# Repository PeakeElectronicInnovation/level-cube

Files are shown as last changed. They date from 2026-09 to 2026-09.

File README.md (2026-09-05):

# Level Cube

A pocket-sized two-axis spirit level. An ADXL345 accelerometer measures tilt and an 8x7 matrix of
WS2812B LEDs shows a "bubble" that drifts toward the high side of whatever surface the cube is
resting on. Green means level, amber means close, red means off. One button does everything.

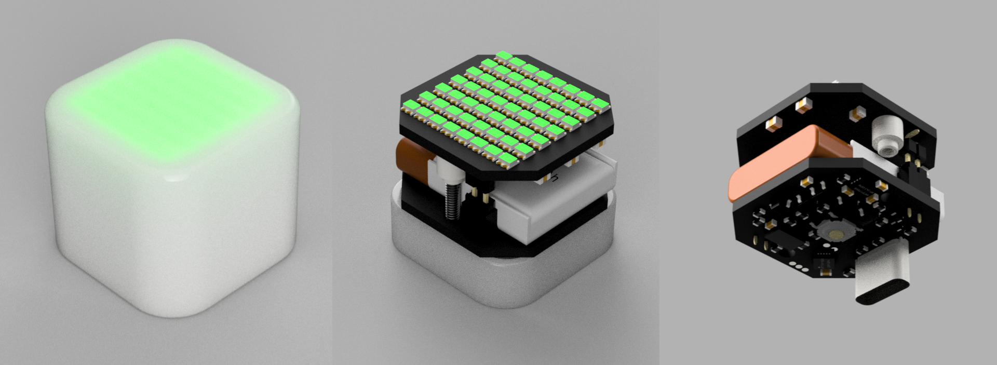
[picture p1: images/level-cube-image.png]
Level Cube - enclosure, LED matrix, main PCB


Firmware runs on an ATtiny1606 (16 KB flash, 1 KB RAM) using PlatformIO + megaTinyCore, powered by a
single LiPo cell with USB-C charging.

---

## Contents

- [Features](#features)
- [Using it](#using-it)
- [Hardware](#hardware)
- [Firmware](#firmware)
- [Building and flashing](#building-and-flashing)
- [Tuning](#tuning)
- [Repository layout](#repository-layout)
- [Credits and licence](#credits-and-licence)

---

## Features

- Two-axis level with a smoothly interpolated bubble (sub-pixel positioning across 2x2 LEDs).
- Works on any face of the cube: the button selects which sensor axis is "up" (X/Y/Z), the
  firmware works out whether the board is right-way-up or flipped and rotates the display so the
  UI always reads correctly.
- Per-orientation zero calibration stored in EEPROM, so the bubble reads dead centre on a known
  level surface for each of the five supported orientations.
- Soft power latch: a momentary button press turns the cube on, the MCU holds itself on, and either
  a long press or one minute of stillness turns it off (near-zero standby draw).
- Battery gauge on power-up, low-battery cut-off, USB-C LiPo charging.
- Whole thing runs in 337 bytes of RAM and 7.5 KB of flash. No floating point in the main loop.

---

## Using it

### Power on

Press the button. The cube shows:

1. **Battery gauge** - a horizontal bar across the middle row for ~0.7 s. Green above 50 %,
   amber 20-50 %, red below 20 %. If the cell is below 3.4 V the display flashes red three times
   and the cube turns itself off again.
2. **Axis glyph** - a large `X`, `Y` or `Z` for 0.5 s showing which sensor axis has been chosen as
   "up". On power-up this is auto-detected from gravity.
3. **Level display**.

### Level display

- Dim white **ticks** at the centre of each edge mark the level position.
- The **bubble** moves toward the high side of the surface, like a real spirit level. Full-scale
  deflection (bubble reaching the edge) is about 10 degrees.
- Bubble colour: **green** within ~1 degree, **amber** within ~3 degrees, **red** beyond that.

### Button

| Action | Result |
|---|---|
| Short press (< 2 s) | Cycle the "up" axis X -> Y -> Z. The glyph is shown briefly. |
| Hold 2-5 s, release | Power off. A **white** bar fills along the bottom row while held. |
| Hold > 5 s, release | Start calibration. The bar turns **red** during 2-5 s, then **blue** once 5 s is passed. |

The bar gives you feedback so you know which action you will get when you let go.

### Orientation

The ADXL345 has three axes. Whichever one is chosen as "up" is ignored for levelling; the other two
drive the bubble. For X and Y the sign of gravity along the up axis is detected automatically (with
0.5 g of hysteresis so it doesn't flicker), giving five cases:

| Case | Up axis | Bubble columns from | Bubble rows from | Display rotation |
|---|---|---|---|---|
| 0 | +X | Z | Y | column 0 at top |
| 1 | -X | Z | Y | column 7 at top |
| 2 | +Y | X | Z | normal |
| 3 | -Y | X | Z | 180 degrees |
| 4 | Z (either sign) | X | Y | normal (board flat) |

Case 4 is the "cube sitting on its base" case. Cases 0-3 are for standing the cube on a side and
using an edge as the reference. The mapping and signs are in `AXIS_MAP` in `include/config.h`.

### Calibration

Each of the five cases has its own pair of zero offsets. To calibrate:

1. Select the axis you want to calibrate (short presses until the correct glyph shows).
2. Hold the button until the hold bar turns blue (> 5 s), then release.
3. A **5-4-3-2-1 countdown** is shown. Put the cube down on your reference surface and take your
   hands off it.
4. A blue dot chases around the perimeter for 1.5 s while 150 raw samples are averaged; a blue bar
   in the centre row shows progress.
5. A green **tick** confirms the offsets have been saved to EEPROM.

The offsets are applied immediately and survive power cycles. Calibrating one case does not affect
the others.

### Auto power off

If no axis changes by more than ~0.7 degrees for 60 seconds (checked every 500 ms), and the
button hasn't been touched, the cube powers itself off.

---

## Hardware

Two PCBs stacked inside a translucent cube enclosure that acts as the diffuser. Design files
(Altium) and a PDF of the schematics are in `hardware/`.

| | |
|---|---|
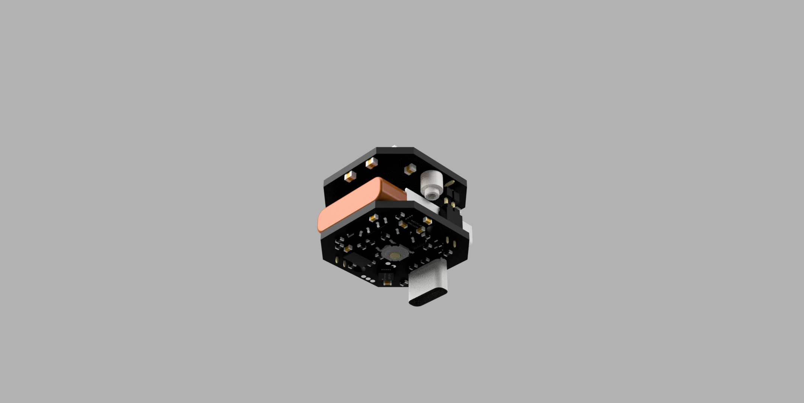
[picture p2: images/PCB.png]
Main PCB
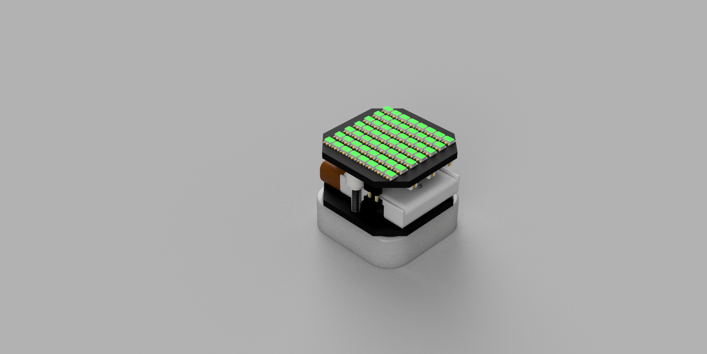
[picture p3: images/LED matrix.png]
LED matrix
|  |  |
| Main board (underside): MCU, accelerometer, charger, USB-C, button | LED panel stacked on pin headers above the main board and battery |

### Main board

| Function | Part | Notes |
|---|---|---|
| MCU | **ATtiny1606** (QFN20) | 16 KB flash, 1 KB SRAM, 256 B EEPROM. Programmed via UPDI on PA0. |
| Accelerometer | **ADXL345BCCZ** | I2C, address `0x53` (SDO/ALT pulled low). INT1/INT2 routed to PA5/PA6 but not used. |
| LiPo charger | **MCP73832** | PROG = 5.1 k -> ~200 mA charge current. STAT output to PC3. |
| 3.3 V regulator | **LR7533** LDO | Powers the MCU and accelerometer (`+3.3`). |
| Charge port | **USB-C** receptacle | Power only. 5.1 k pull-downs on CC1/CC2 so a C-to-C cable supplies 5 V. |
| Power latch | PMOS Q1 + NMOS Q3 | See below. |
| LED power switch | PMOS Q2 + NMOS Q4 | LED matrix supply is switched separately from the MCU. |
| Button | SW1 | Momentary, active low, to PC2 (internal pull-up). |
| Battery sense | 100 k / 100 k divider | VBAT/2 to PA1. |
| USB sense | 100 k / 100 k divider | VBUS/2 to PA2 (not currently used by firmware). |
| Battery | single LiPo cell on solder pads | Nominal 3.7 V. |

### Power path

```
                  Q1 (PMOS)                      Q2 (PMOS)
  VBAT ───────────┬──────┬── VMCU ── LR7533 ── +3.3 (MCU, ADXL345)
                  │      │
                  │      └──────────┬── VLED ── WS2812B matrix (56x)
                  │                 │
            gate ─┴─ R1 100k        gate ─ R7 100k
              │                       │
       ┌──────┴──────┐             Q4 (NMOS) <── LED_PWR (PC1)
   D1 ─┤             │
   SW1 (button)   Q3 (NMOS) <── PWR (PC0)
```

- **Power on**: pressing the button pulls Q1's gate low through D1, powering the MCU. The very
  first thing `setup()` does is drive `PWR` (PC0) high, which turns on Q3 and keeps Q1 on after
  the button is released.
- **Power off**: the firmware drives `PWR` low. Q1 turns off and everything downstream of it loses
  power. Standby current is just the leakage through the charger and the FET.
- **LEDs**: the matrix is fed straight from the battery through Q2, enabled by `LED_PWR` (PC1).
  The 3.3 V data line drives the first WS2812B directly. The firmware turns the LED supply off
  (after clearing the frame) before pulling `PWR` low, so the matrix never sees a dirty shutdown.

### LED panel

A separate board carrying **56 x WS2812B** in an 8 wide x 7 tall grid, chained in a single
string, addressed left to right and top to bottom (LED index = `y * 8 + x`). It plugs onto the main
board via pin headers: `L_V+`, `L_GND` and `LED_DAT`.

At full white the matrix could draw around 3 A, so the firmware caps brightness (bubble 48/255,
UI elements 24/255, ticks 3/255). Through the diffuser this is plenty.

### MCU pin map

| Pin | Signal | Direction | Use |
|---|---|---|---|
| PA0 | UPDI | - | Programming/debug |
| PA1 | BATT_VOLTS | analog in | Battery voltage, VBAT/2 |
| PA2 | USB_VOLTS | analog in | VBUS/2 (unused) |
| PA3 | SPI0 SCK | internal | Bit clock for the LED driver, not routed off-chip |
| PA4 | ANA_FLOAT | - | Spare, floating |
| PA5 | AXL_INT1 | in (pull-up) | ADXL345 INT1 (unused) |
| PA6 | AXL_INT2 | in (pull-up) | ADXL345 INT2 (unused) |
| PA7 | LED_DAT | out | WS2812B data, CCL LUT1 output |
| PB0 | SCL | I2C | ADXL345 |
| PB1 | SDA | I2C | ADXL345 |
| PB2 | TX | out | Debug UART, 115200 (only when built with `-DDEBUG`) |
| PB3 | RX | in | Debug UART |
| PC0 | PWR | out | Power latch, drive high to stay on |
| PC1 | LED_PWR | out | LED matrix supply enable |
| PC2 | BUTTON | in (pull-up) | Active low |
| PC3 | CC_STAT | in (pull-up) | MCP73832 charge status (read, not yet displayed) |

---

## Firmware

### Overview

```
src/main.cpp       power latch, button state machine, orientation, calibration, auto-off, UI
src/display.*      LED frame buffer, drawing primitives, WS2812B output via CCL + SPI + TCB0
src/accel.*        minimal ADXL345 driver and EMA filter
include/config.h   pins, timings, thresholds, AXIS_MAP
include/characters.h  4x6 glyphs for digits and X/Y/Z
lib/SmoothLedCcl/  vendored WS2812 bit-banging-free driver (see below)
```

The main loop is cooperative and non-blocking: poll the accelerometer at 100 Hz, poll the button,
check for movement, check the battery every 5 s, and render a frame every 25 ms (~40 Hz).

### LED driving without bit-banging

Generating WS2812B timing on an 8-bit part while doing anything else is awkward. This project uses
the approach from Matt Shepcar's [SmoothLed](https://github.com/mattshepcar/SmoothLed): the
**SPI0** peripheral shifts the pixel bytes out, an event channel feeds SCK into **TCB0** in
single-shot mode to produce the "1-bit" pulse width, and a **CCL** look-up table (LUT1, output on
PA7) combines SCK, MOSI and the TCB output into a valid WS2812B waveform. The CPU's only job is to
refill the SPI data register from an interrupt (`ISR(SPI0_INT_vect)` in `display.cpp`), which is
why the bytes are written inverted (the LUT expects `!MOSI`).

The result is that a full 168-byte frame streams out in the background while the main loop keeps
running. `display_show()` starts a transfer; every drawing call waits for any in-flight transfer to
finish before touching the buffer.

`SmoothLedCcl.h` is vendored in `lib/SmoothLedCcl/` rather than pulled from the registry because
the upstream `PC0_SPI0_ASYNCCH2` branch references `EVSYS_ASYNCCH2`, which tinyAVR **0-series**
parts don't have. The vendored copy guards that branch so it compiles on the ATtiny1606.

TCB0 is taken by the LED driver, so `millis()` must run on TCA0. The PlatformIO board definition
for the ATtiny1606 already defines `MILLIS_USE_TIMERA0`; if you build with a different board or
core configuration, make sure that define is present or the two will fight over TCB0.

### Coordinate systems

`display.h` keeps two frames of reference:

- **Board coordinates** are fixed to the PCB (x 0-7, y 0-6). The bubble is drawn here because its
  position is physically meaningful no matter how the cube is held.
- **View coordinates** are what the person looking at the cube sees after the current rotation
  is applied. Glyphs, bars, ticks and the perimeter chaser are drawn here so they always appear
  upright. For the two 90 degree cases the view is 7 wide by 8 tall.

### Accelerometer and filtering

The ADXL345 runs at 100 Hz in full-resolution +/-2 g mode (3.9 mg/LSB, so 1 g is ~256 LSB). Each
axis is smoothed with an exponential moving average in Q8 fixed point:

```
y += (x - y) >> 4        // tau ~ 160 ms at 100 Hz
```

Tilt is then handled as Q4 LSB values. For small angles `LSB ~= 256 * sin(angle)`, which is where
the thresholds in `config.h` come from (4.5 LSB ~ 1 degree, 13.4 LSB ~ 3 degrees, 45 LSB ~ 10
degrees). Calibration averages *raw* (unfiltered) samples over the 1.5 s window so the filter's
lag doesn't bias the result.

### EEPROM layout

| Address | Contents |
|---|---|
| 0 | Magic byte `0xA5` (offsets valid) |
| 1-20 | `int16_t calOffset[5][2]` - per case `[col, row]` zero offsets in Q4 LSB |

If the magic byte is missing all offsets are treated as zero.

### Resource usage

```
RAM:   337 / 1024 bytes  (168 of which is the LED frame buffer)
Flash: 7550 / 16384 bytes
```

---

## Building and flashing

Requires [PlatformIO](https://platformio.org/) (CLI or VS Code extension). The `atmelmegaavr`
platform and megaTinyCore are fetched automatically on first build.

```sh
pio run                  # build
pio run -t upload        # flash via UPDI (Atmel-ICE by default, see platformio.ini)
```

Connect the programmer to the UPDI pad (PA0), GND and 3.3 V. To use a different UPDI programmer
(e.g. SerialUPDI, pymcuprog, jtag2updi) change `upload_protocol` in `platformio.ini`.

### Debug output

Build with `DEBUG` defined to get a 115200 baud log on PB2 (power-up, axis changes, case changes,
battery voltage, calibration results, and periodic tilt values):

```powershell
$env:PLATFORMIO_BUILD_FLAGS="-DDEBUG"; pio run -t upload
pio device monitor
```

or uncomment `-DDEBUG` under `build_flags` in `platformio.ini`.

There are no automated tests - everything is verified on the hardware.

---

## Tuning

Everything adjustable lives in `include/config.h`:

| Constant | Default | Meaning |
|---|---|---|
| `TILT_FULL_SCALE_LSB` | 45 (~10 deg) | Tilt that puts the bubble at the edge of the matrix |
| `TILT_LEVEL_LSB` | 4.5 (~1 deg) | Bubble turns green inside this radius |
| `TILT_NEAR_LSB` | 13.4 (~3 deg) | Amber inside this, red beyond |
| `ACCEL_FILTER_SHIFT` | 4 | EMA strength; higher = smoother but slower |
| `BUBBLE_BRIGHTNESS` etc. | 48 / 24 / 3 | Per-channel brightness caps |
| `BUTTON_POWER_OFF_MS` | 2000 | Hold time for power off |
| `BUTTON_CALIBRATE_MS` | 5000 | Hold time for calibration |
| `AUTO_OFF_MS` | 60000 | Stillness before auto power off |
| `MOVE_THRESHOLD_LSB` | 3 (~0.7 deg) | Change that counts as movement |
| `V_BAT_MIN_MV` / `V_BAT_FULL_MV` | 3400 / 4150 | Battery gauge end points and cut-off |
| `CAL_COUNTDOWN_MS` / `CAL_SAMPLE_MS` | 5000 / 1500 | Calibration countdown and averaging window |
| `AXIS_MAP` | - | Axis mapping, signs and rotation per orientation case |

If the bubble moves the wrong way for a given orientation, flip the relevant `colSign`/`rowSign`
in `AXIS_MAP`; if the UI is drawn on its side or upside down, change that case's `rotation`.

---

## Repository layout

```
.
├── src/                  firmware sources (main, display, accel)
├── include/              config.h, characters.h
├── lib/SmoothLedCcl/     vendored WS2812 CCL driver (MIT) with 0-series fix
├── hardware/             Altium project, schematics (.SchDoc), PCB (.PcbDoc), schematic PDF
├── images/               renders used in this README
├── platformio.ini        build configuration (Upload_UPDI env)
└── AGENTS.md             short orientation notes for AI coding assistants
```

---

## Credits and licence

- WS2812 CCL/SPI driver technique and `SmoothLedCcl.h`: Matt Shepcar,
  [mattshepcar/SmoothLed](https://github.com/mattshepcar/SmoothLed), MIT licence
  (see `lib/SmoothLedCcl/LICENSE`).
- Arduino core: [megaTinyCore](https://github.com/SpenceKonde/megaTinyCore) by Spence Konde.
- Hardware and firmware: Peake Electronic Innovation.

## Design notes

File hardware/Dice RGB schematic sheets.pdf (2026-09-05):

Main Power Switch | LED Power Switch | Charge Port USB C Connector

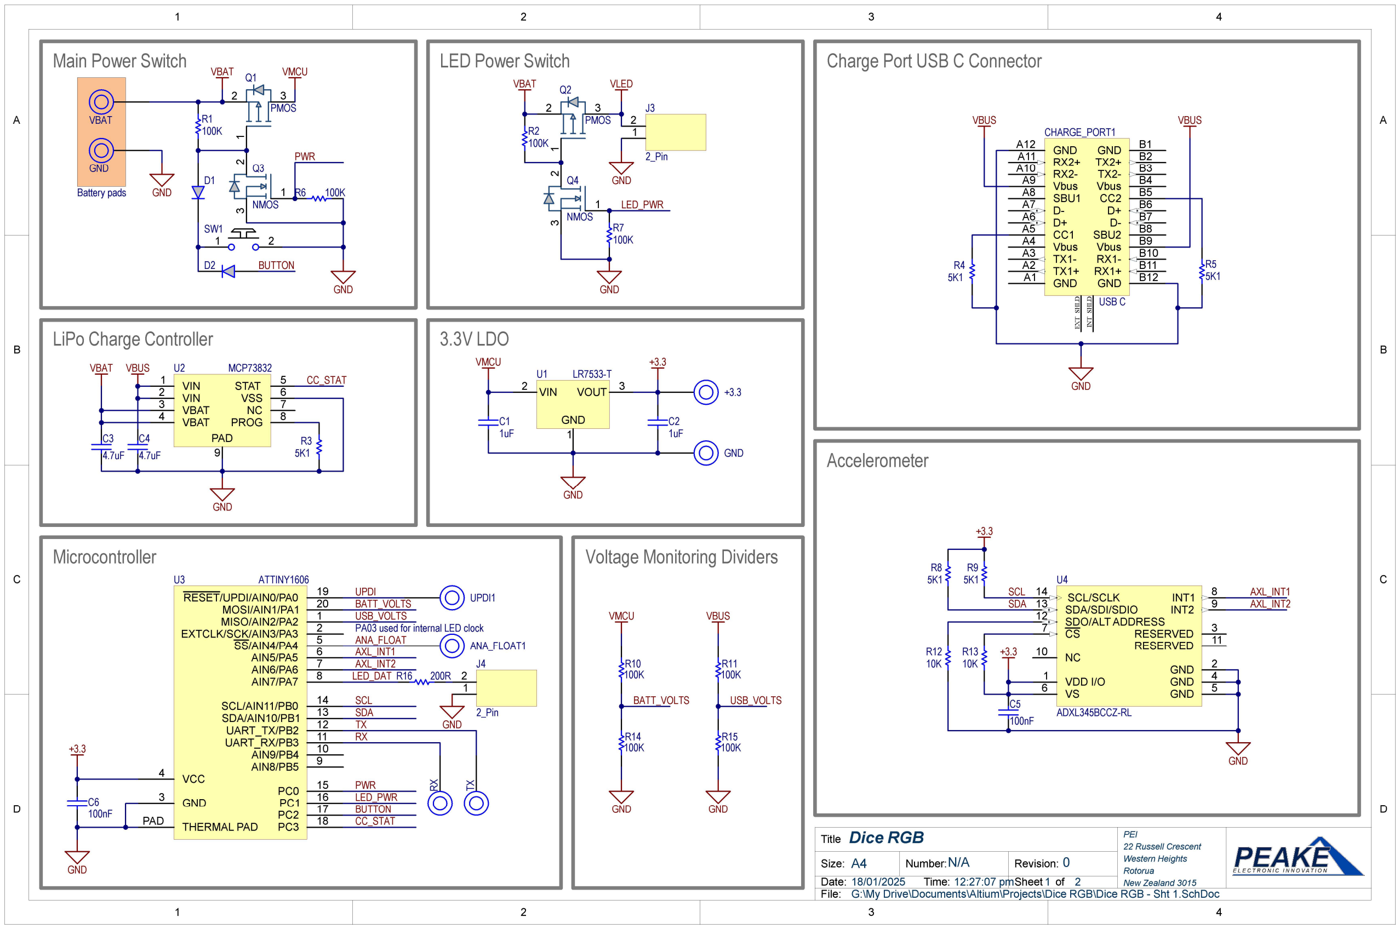
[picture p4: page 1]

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
### 22 Russell Crescent

Western Heights
Rotorua

### 2 New Zealand 3015

## Dice RGB

N/A | 0
18/01/2025 | 12:27:07 pm
G:\My Drive\Documents\Altium\Projects\Dice RGB\Dice RGB - Sht 1.SchDoc

Title

Size: | Number:
Date:
File:

Revision:
Time: | Sheet of

A4

VIN 1
VIN 2
VBAT 3
VBAT 4
STAT | 5
VSS | 6
NC | 7
PROG | 8

PAD
9
U2 | MCP73832
MISO/AIN2/PA2 | 1
EXTCLK/SCK/AIN3/PA3 | 2

GND 3

VCC 4

SS/AIN4/PA4 | 5
AIN5/PA5 | 6
AIN6/PA6 | 7
AIN7/PA7 | 8
AIN8/PB5 | 9
AIN9/PB4 | 10 UART_RX/PB3 | 11 UART_TX/PB2 | 12 SDA/AIN10/PB1 | 13 SCL/AIN11/PB0 | 14
PC0 | 15
PC1 | 16
PC2 | 17
PC3 | 18
RESET/UPDI/AIN0/PA0 | 19
MOSI/AIN1/PA1 | 20

THERMAL PAD PAD

U3 | ATTINY1606

100nF

C6

GND

UPDI1 UPDI

CC_STAT

VIN 2

GND
1

VOUT 3

U1 LR7533-T

VDD I/O 1

GND | 2
RESERVED | 3
GND | 4
GND | 5 VS 6

CS 7

| INT1 | 8
| INT2 | 9
NC 10 | RESERVED | 11
SDO/ALT ADDRESS 12 | SDA/SDI/SDIO 13 | SCL/SCLK 14

U4

ADXL345BCCZ-RL

VMCU

1uF

C1
1uF

C2

+3.3

GND

+3.3

GND A1 | TX1+ A2 | TX1- A3 | Vbus A4 | CC1 A5 | D+ A6 | D- A7 | SBU1 A8 | Vbus A9 | RX2- A10 | RX2+ A11 | GND A12 | GND | B1
| | | | | | | | | | | | TX2+ | B2
| | | | | | | | | | | | TX2- | B3
| | | | | | | | | | | | Vbus | B4
Vbus | B9
CC2 | B5
D+ | B6
D- | B7
SBU2 | B8
RX1- | B10
RX1+ | B11
GND | B12 EXT_SHLD INT_SHLD

CHARGE_PORT1

USB C

5K1

R4
5K1

R5

GND

VBUS | VBUS

VBAT VBUS

GND

5K1

R3
4.7uF

C3
4.7uF

C4

CC_STAT

GND

AXL_INT1
AXL_INT2

+3.3

100nF

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
+3.3

100K

R10

100K

R14

GND

VMCU

BATT_VOLTS

BATT_VOLTS

100K

R11

100K

R15

GND

VBUS

USB_VOLTS

USB_VOLTS

1

2 3

Q1

PMOS

VBAT

GND

100K

R1

D1

1 2

SW1

GND

BUTTON

VMCU

BUTTON

PWR
LED_PWR | RX | TX

### 1 ² 3

Q3

NMOS

R6 100K

D2

VBAT

GND | 1 2 3 Q2

PMOS

VLED

### 1 ² 3

Q4

NMOS

LED_PWR

100K

R7

1

2

J3

2_Pin

GND

100K

R2

VBAT

PWR

GND

ANA_FLOAT | ANA_FLOAT1 AXL_INT1

AXL_INT2
LED_DAT

PA03 used for internal LED clock

+3.3

GND

1

2

J4

2_Pin
GND
LiPo Charge Controller | 3.3V LDO
Microcontroller | Voltage Monitoring Dividers

# Accelerometer

Battery pads

R16 200R

TX
RX

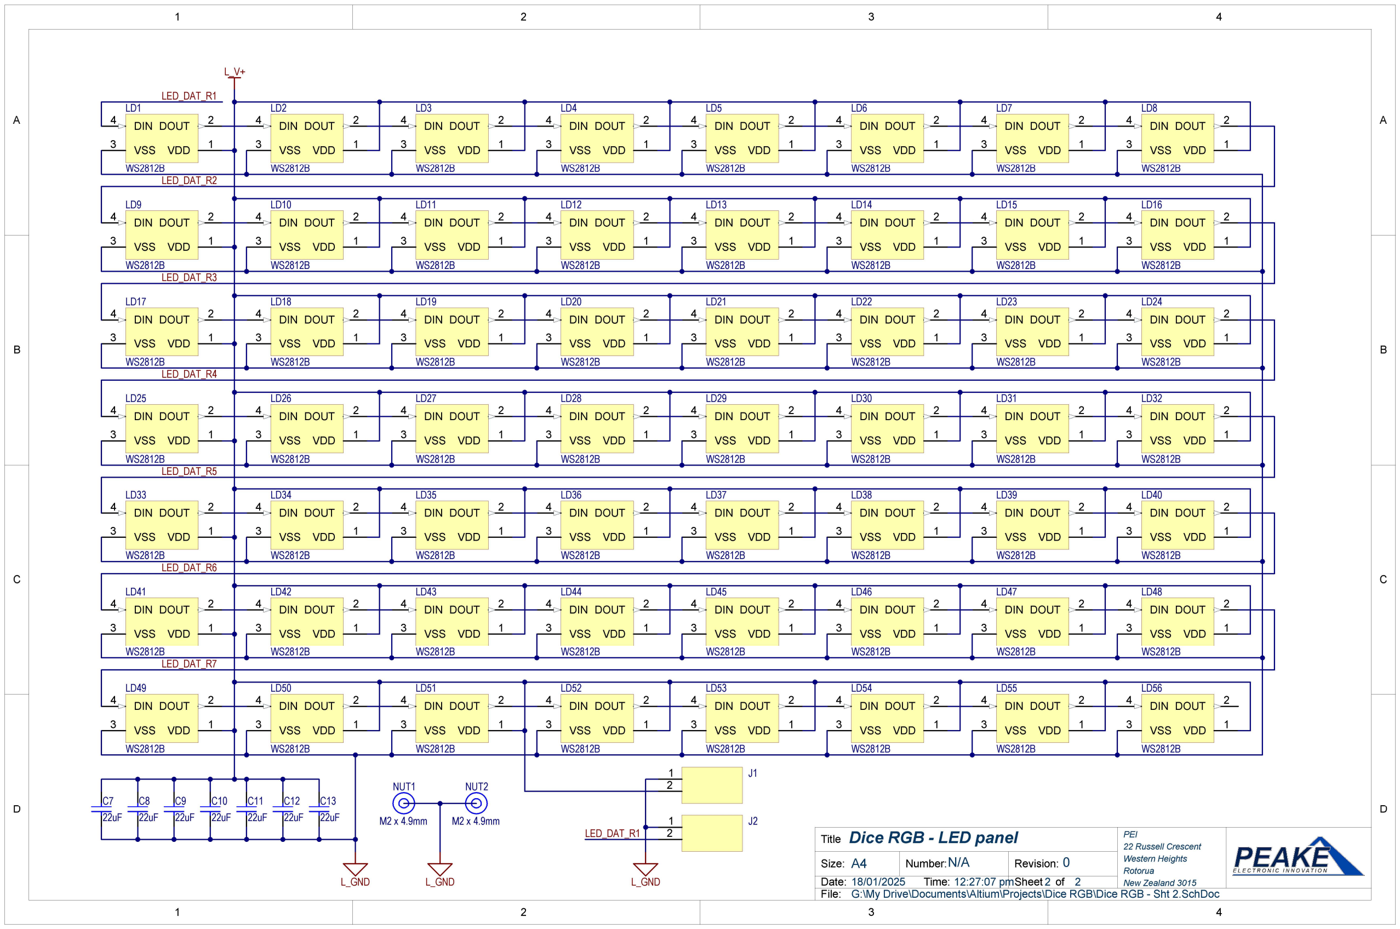
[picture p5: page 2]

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
### 22 Russell Crescent

Western Heights
Rotorua

### 2 New Zealand 3015

## Dice RGB - LED panel

N/A | 0
18/01/2025 | 12:27:07 pm
G:\My Drive\Documents\Altium\Projects\Dice RGB\Dice RGB - Sht 2.SchDoc

Title

Size: | Number:
Date:
File:

Revision:
Time: | Sheet of

A4

VDD | 1
DOUT | 2

VSS 3

DIN 4

LD1

WS2812B

VDD | 1
DOUT | 2

VSS 3

DIN 4

LD2

WS2812B

VDD | 1
DOUT | 2

VSS 3

DIN 4

LD3

WS2812B

VDD | 1
DOUT | 2

VSS 3

DIN 4

LD4

WS2812B

VDD | 1
DOUT | 2

VSS 3

DIN 4

LD5

WS2812B

VDD | 1
DOUT | 2

VSS 3

DIN 4

LD6

WS2812B

VDD | 1
DOUT | 2

VSS 3

DIN 4

LD7

WS2812B

L_V+

LED_DAT_R1

L_GND

VDD | 1
DOUT | 2

VSS 3

DIN 4

LD9

WS2812B

VDD | 1
DOUT | 2

VSS 3

DIN 4

LD10

WS2812B

VDD | 1
DOUT | 2

VSS 3

DIN 4

LD11

WS2812B

VDD | 1
DOUT | 2

VSS 3

DIN 4

LD12

WS2812B

VDD | 1
DOUT | 2

VSS 3

DIN 4

LD13

WS2812B

VDD | 1
DOUT | 2

VSS 3

DIN 4

LD14

WS2812B

VDD | 1
DOUT | 2

VSS 3

DIN 4

LD15

WS2812B

LED_DAT_R2

VDD | 1
DOUT | 2

VSS 3

DIN 4

LD17

WS2812B

VDD | 1
DOUT | 2

VSS 3

DIN 4

LD18

WS2812B

VDD | 1
DOUT | 2

VSS 3

DIN 4

LD19

WS2812B

VDD | 1
DOUT | 2

VSS 3

DIN 4

LD20

WS2812B

VDD | 1
DOUT | 2

VSS 3

DIN 4

LD21

WS2812B

VDD | 1
DOUT | 2

VSS 3

DIN 4

LD22

WS2812B

VDD | 1
DOUT | 2

VSS 3

DIN 4

LD23

WS2812B

VDD | 1
DOUT | 2

VSS 3

DIN 4

LD25

WS2812B

VDD | 1
DOUT | 2

VSS 3

DIN 4

LD26

WS2812B

VDD | 1
DOUT | 2

VSS 3

DIN 4

LD27

WS2812B

VDD | 1
DOUT | 2

VSS 3

DIN 4

LD28

WS2812B

VDD | 1
DOUT | 2

VSS 3

DIN 4

LD29

WS2812B

VDD | 1
DOUT | 2

VSS 3

DIN 4

LD30

WS2812B

VDD | 1
DOUT | 2

VSS 3

DIN 4

LD31

WS2812B

VDD | 1
DOUT | 2

VSS 3

DIN 4

LD33

WS2812B

VDD | 1
DOUT | 2

VSS 3

DIN 4

LD34

WS2812B

VDD | 1
DOUT | 2

VSS 3

DIN 4

LD35

WS2812B

VDD | 1
DOUT | 2

VSS 3

DIN 4

LD36

WS2812B

VDD | 1
DOUT | 2

VSS 3

DIN 4

LD37

WS2812B

VDD | 1
DOUT | 2

VSS 3

DIN 4

LD38

WS2812B

VDD | 1
DOUT | 2

VSS 3

DIN 4

LD39

WS2812B

VDD | 1
DOUT | 2

VSS 3

DIN 4

LD41

WS2812B

VDD | 1
DOUT | 2

VSS 3

DIN 4

LD42

WS2812B

VDD | 1
DOUT | 2

VSS 3

DIN 4

LD43

WS2812B

VDD | 1
DOUT | 2

VSS 3

DIN 4

LD44

WS2812B

VDD | 1
DOUT | 2

VSS 3

DIN 4

LD45

WS2812B

VDD | 1
DOUT | 2

VSS 3

DIN 4

LD46

WS2812B

VDD | 1
DOUT | 2

VSS 3

DIN 4

LD47

WS2812B

VDD | 1
DOUT | 2

VSS 3

DIN 4

LD49

WS2812B

VDD | 1
DOUT | 2

VSS 3

DIN 4

LD50

WS2812B

VDD | 1
DOUT | 2

VSS 3

DIN 4

LD51

WS2812B

VDD | 1
DOUT | 2

VSS 3

DIN 4

LD52

WS2812B

VDD | 1
DOUT | 2

VSS 3

DIN 4

LD53

WS2812B

VDD | 1
DOUT | 2

VSS 3

DIN 4

LD54

WS2812B

VDD | 1
DOUT | 2

VSS 3

DIN 4

LD55

WS2812B

LED_DAT_R3

LED_DAT_R4

LED_DAT_R5

LED_DAT_R6

LED_DAT_R7

22uF

C7
22uF

C8
22uF

C9
22uF

C10
22uF

C11

VDD | 1
DOUT | 2

VSS 3

DIN 4

LD8

WS2812B

VDD | 1
DOUT | 2

VSS 3

DIN 4

LD16

WS2812B

VDD | 1
DOUT | 2

VSS 3

DIN 4

LD24

WS2812B

VDD | 1
DOUT | 2

VSS 3

DIN 4

LD32

WS2812B

VDD | 1
DOUT | 2

VSS 3

DIN 4

LD40

WS2812B

VDD | 1
DOUT | 2

VSS 3

DIN 4

LD48

WS2812B

VDD | 1
DOUT | 2

VSS 3

DIN 4

LD56

WS2812B

22uF

C12
22uF

C13

NUT1

M2 x 4.9mm

NUT2

M2 x 4.9mm

1
2

J1

1
2

J2
LED_DAT_R1
L_GND | L_GND

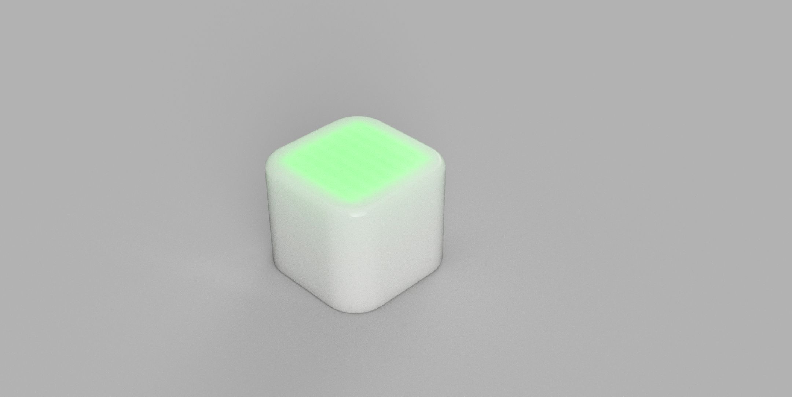
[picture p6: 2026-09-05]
images/Enclosure - top.png

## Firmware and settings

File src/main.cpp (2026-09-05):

#include <Arduino.h>
#include <EEPROM.h>
#include "config.h"
#include "characters.h"
#include "display.h"
#include "accel.h"

//----------------------------------- State ---------------------------------------------//

enum UiMode : uint8_t { UI_BATTERY, UI_GLYPH, UI_CAL_COUNTDOWN, UI_CAL_SAMPLING, UI_CAL_DONE, UI_LEVEL };

static UiMode uiMode = UI_BATTERY;
static unsigned long uiUntil = 0, uiStart = 0;

static uint8_t upAxis = 2;               // sensor axis pointing up (0=X 1=Y 2=Z), button selected
static bool upNegative = false;          // gravity along upAxis is negative (board flipped), auto
static uint8_t activeCase = 4;           // index into AXIS_MAP, derived from the two above
static int16_t calOffset[NUM_CASES][2];  // per case: [col, row] zero offsets, Q4 LSB
static int32_t calSum[2];                // accumulators while sampling
static uint16_t calCount = 0;

// 7x7 tick, fits either rotation
static const uint8_t tickBitmap[7] = { 0x00, 0x40, 0x20, 0x11, 0x0A, 0x04, 0x00 };

// Button
static bool btnRawLast = true, btnDown = true, btnInitialPress = true;
static unsigned long btnChangeAt = 0, btnPressAt = 0;

// Auto power off
static unsigned long lastMoveAt = 0, nextMoveCheck = 0;
static int16_t moveRef[3];

// Battery
static unsigned long nextBattCheck = 0;
static uint8_t battPercent = 100;

static unsigned long nextFrame = 0;

//----------------------------------- Power ---------------------------------------------//

static void powerDown() {
  DBGLN("Power down");
  display_off();
  while (!digitalRead(BUTTON_PIN));
  digitalWrite(PWR_PIN, LOW);
  while (1);
}

//----------------------------------- Battery -------------------------------------------//

static uint16_t readBatteryMv() {
  uint32_t raw = analogRead(BATT_VOLTS_PIN);
  return (uint16_t)(raw * 5000UL / 1024UL);
}

static void checkBattery() {
  uint16_t mv = readBatteryMv();
  DBG("Vbat mV: "); DBGLN(mv);
  if (mv < V_BAT_MIN_MV) {
    for (uint8_t i = 0; i < 3; i++) {
      display_fill(BAR_BRIGHTNESS, 0, 0); display_show(); delay(150);
      display_clear(); display_show(); delay(150);
    }
    powerDown();
  }
  int32_t pct = ((int32_t)mv - V_BAT_MIN_MV) * 100L / (V_BAT_FULL_MV - V_BAT_MIN_MV);
  battPercent = pct < 0 ? 0 : pct > 100 ? 100 : (uint8_t)pct;
}

//----------------------------------- Calibration ---------------------------------------//

static void loadCalibration() {
  if (EEPROM.read(EEPROM_ADDR_MAGIC) == EEPROM_MAGIC) {
    EEPROM.get(EEPROM_ADDR_CAL, calOffset);
  } else {
    memset(calOffset, 0, sizeof(calOffset));
  }
}

static void saveCalibration() {
  EEPROM.put(EEPROM_ADDR_CAL, calOffset);
  EEPROM.update(EEPROM_ADDR_MAGIC, EEPROM_MAGIC);
}

//----------------------------------- Orientation ---------------------------------------//

// Re-evaluate which of the 5 cases applies. The up axis comes from the button, its sign from
// gravity (with hysteresis so it only flips once the board is clearly turned over).
static void updateOrientation() {
  if (upAxis == 2) {
    upNegative = false;
  } else {
    int16_t g = accel_filtered(upAxis) >> 8;
    if (g > UP_SIGN_THRESHOLD_LSB) upNegative = false;
    else if (g < -UP_SIGN_THRESHOLD_LSB) upNegative = true;
  }
  uint8_t c = upAxis == 2 ? 4 : upAxis * 2 + (upNegative ? 1 : 0);
  if (c != activeCase) {
    activeCase = c;
    display_setRotation(AXIS_MAP[c].rotation);
    DBG("Case: "); DBGLN(c);
  }
}

//----------------------------------- Level maths ---------------------------------------//

// Signed, mapped tilt for the current case in Q4 LSB, before calibration offset
static int16_t mappedTilt(uint8_t axis, int8_t sign) {
  return (int16_t)((accel_filtered(axis) >> 4) * sign);
}

static void getTilt(int16_t &col, int16_t &row) {
  const AxisMap &m = AXIS_MAP[activeCase];
  col = mappedTilt(m.colAxis, m.colSign) - calOffset[activeCase][0];
  row = mappedTilt(m.rowAxis, m.rowSign) - calOffset[activeCase][1];
}

static void setUi(UiMode mode, unsigned long duration) {
  uiMode = mode;
  uiStart = millis();
  uiUntil = uiStart + duration;
}

static bool calibrating() {
  return uiMode == UI_CAL_COUNTDOWN || uiMode == UI_CAL_SAMPLING || uiMode == UI_CAL_DONE;
}

static void startCalibration() {
  DBGLN("Calibration countdown");
  setUi(UI_CAL_COUNTDOWN, CAL_COUNTDOWN_MS);
}

// Called for every new accelerometer sample while sampling: accumulate mapped raw values (Q4)
static void calibrationSample() {
  const AxisMap &m = AXIS_MAP[activeCase];
  calSum[0] += ((int32_t)accel_raw(m.colAxis) << 4) * m.colSign;
  calSum[1] += ((int32_t)accel_raw(m.rowAxis) << 4) * m.rowSign;
  calCount++;
}

static void finishCalibration() {
  if (calCount) {
    calOffset[activeCase][0] = calSum[0] / (int32_t)calCount;
    calOffset[activeCase][1] = calSum[1] / (int32_t)calCount;
    saveCalibration();
  }
  DBG("Calibrated from "); DBG(calCount); DBGLN(" samples");
}

//----------------------------------- UI ------------------------------------------------//

static void showGlyph() { setUi(UI_GLYPH, GLYPH_SHOW_MS); }

static void drawLevel() {
  int16_t col, row;
  getTilt(col, row);

  // Bubble travels toward the high side; position scaled so TILT_FULL_SCALE_LSB = half width
  const int16_t centreX = (MATRIX_W - 1) * 8;    // 3.5 px in Q4
  const int16_t centreY = (MATRIX_H - 1) * 8;    // 3.0 px in Q4
  const int32_t scaleNum = (MATRIX_W - 1) * 8;
  const int32_t scaleDen = (int32_t)TILT_FULL_SCALE_LSB * 16;
  int16_t x = centreX + (int16_t)((int32_t)col * scaleNum / scaleDen);
  int16_t y = centreY + (int16_t)((int32_t)row * scaleNum / scaleDen);

  const int32_t levelSq = (int32_t)(TILT_LEVEL_LSB * 16 * TILT_LEVEL_LSB * 16);
  const int32_t nearSq  = (int32_t)(TILT_NEAR_LSB * 16 * TILT_NEAR_LSB * 16);
  int32_t d2 = (int32_t)col * col + (int32_t)row * row;

  uint8_t r, g, b = 0;
  if (d2 < levelSq)     { r = 0;                 g = BUBBLE_BRIGHTNESS; }
  else if (d2 < nearSq) { r = BUBBLE_BRIGHTNESS; g = BUBBLE_BRIGHTNESS / 2; }
  else                  { r = BUBBLE_BRIGHTNESS; g = 0; }

  display_clear();
  display_drawTicks();
  display_drawBubble(x, y, r, g, b);
}

static void drawHoldBar(unsigned long held) {
  const uint8_t w = display_viewW(), bottom = display_viewH() - 1;
  const uint16_t fullQ4 = w * 16;
  uint8_t fill, r, g, b;
  if (held < BUTTON_POWER_OFF_MS) {
    fill = held * fullQ4 / BUTTON_POWER_OFF_MS;
    r = g = b = BAR_BRIGHTNESS;
  } else if (held < BUTTON_CALIBRATE_MS) {
    fill = (held - BUTTON_POWER_OFF_MS) * fullQ4 / (BUTTON_CALIBRATE_MS - BUTTON_POWER_OFF_MS);
    r = BAR_BRIGHTNESS; g = b = 0;
  } else {
    fill = fullQ4;
    b = BAR_BRIGHTNESS; r = g = 0;
  }
  for (uint8_t x = 0; x < w; x++) display_setPixel(x, bottom, 0, 0, 0);
  display_drawBar(bottom, fill, r, g, b);
}

static void drawBatteryGauge() {
  uint8_t r, g;
  if (battPercent > 50)      { r = 0; g = BAR_BRIGHTNESS; }
  else if (battPercent > 20) { r = BAR_BRIGHTNESS; g = BAR_BRIGHTNESS / 2; }
  else                       { r = BAR_BRIGHTNESS; g = 0; }
  display_clear();
  display_drawBar(display_viewH() / 2, battPercent * (display_viewW() * 16) / 100, r, g, 0);
}

static void drawCountdown(unsigned long now) {
  uint8_t secs = (uiUntil - now) / 1000 + 1;      // 5,4,3,2,1
  if (secs > 9) secs = 9;
  display_clear();
  display_drawGlyph(digit[secs], GLYPH_BRIGHTNESS, GLYPH_BRIGHTNESS, 0);
}

static void drawSampling(unsigned long now) {
  unsigned long elapsed = now - uiStart;
  display_clear();
  // blue dot chasing round the perimeter with a fading tail
  uint8_t head = (elapsed / 40) % PERIMETER_LEN;
  for (uint8_t i = 0; i < 4; i++)
    display_setPerimeterPixel(head + PERIMETER_LEN - i, 0, 0, BAR_BRIGHTNESS >> i);
  // centre row fills as the averaging window progresses
  uint8_t fill = elapsed * (display_viewW() * 16) / CAL_SAMPLE_MS;
  display_drawBar(display_viewH() / 2, fill, 0, 0, BAR_BRIGHTNESS);
}

static void render() {
  unsigned long now = millis();
  if (uiMode != UI_LEVEL && (long)(now - uiUntil) >= 0) {
    switch (uiMode) {
      case UI_BATTERY:
        // Filter has settled during the gauge; pick the starting up axis from gravity
        upAxis = accel_dominantAxis();
        DBG("Up axis: "); DBGLN(upAxis);
        updateOrientation();
        showGlyph();
        break;
      case UI_CAL_COUNTDOWN:
        calSum[0] = calSum[1] = 0;
        calCount = 0;
        setUi(UI_CAL_SAMPLING, CAL_SAMPLE_MS);
        break;
      case UI_CAL_SAMPLING:
        finishCalibration();
        setUi(UI_CAL_DONE, CAL_DONE_MS);
        break;
      default:
        uiMode = UI_LEVEL;
        break;
    }
  }

  switch (uiMode) {
    case UI_BATTERY: drawBatteryGauge(); break;
    case UI_GLYPH:
      display_clear();
      display_drawGlyph(axisGlyph[upAxis], GLYPH_BRIGHTNESS, GLYPH_BRIGHTNESS, GLYPH_BRIGHTNESS);
      break;
    case UI_CAL_COUNTDOWN: drawCountdown(now); break;
    case UI_CAL_SAMPLING:  drawSampling(now); break;
    case UI_CAL_DONE:
      display_clear();
      display_drawBitmap(tickBitmap, 7, 7, 0, BUBBLE_BRIGHTNESS, 0);
      break;
    case UI_LEVEL: drawLevel(); break;
  }
  if (btnDown && !btnInitialPress) drawHoldBar(now - btnPressAt);
  display_show();
}

//----------------------------------- Button --------------------------------------------//

static void onShortPress() {
  upAxis = (upAxis + 1) % 3;
  DBG("Up axis: "); DBGLN(upAxis);
  updateOrientation();
  showGlyph();
}

static void pollButton() {
  unsigned long now = millis();
  bool rawDown = !digitalRead(BUTTON_PIN);
  if (rawDown != btnRawLast) {
    btnRawLast = rawDown;
    btnChangeAt = now;
    return;
  }
  if (rawDown == btnDown || now - btnChangeAt < BUTTON_DEBOUNCE_MS) return;

  btnDown = rawDown;
  lastMoveAt = now;                       // button activity counts as movement
  if (btnDown) {
    btnPressAt = now;
    return;
  }

  // released
  if (btnInitialPress) { btnInitialPress = false; return; }
  unsigned long held = now - btnPressAt;
  if (held >= BUTTON_CALIBRATE_MS) {
    startCalibration();
  } else if (held >= BUTTON_POWER_OFF_MS) {
    powerDown();
  } else if (!calibrating()) {
    onShortPress();
  }
}

//----------------------------------- Auto power off ------------------------------------//

static void pollMovement() {
  unsigned long now = millis();
  if ((long)(now - nextMoveCheck) < 0) return;
  nextMoveCheck = now + MOVE_CHECK_MS;

  bool moved = false;
  for (uint8_t i = 0; i < 3; i++) {
    int16_t cur = accel_filtered(i) >> 8;
    int16_t d = cur - moveRef[i];
    if (d > MOVE_THRESHOLD_LSB || d < -MOVE_THRESHOLD_LSB) { moved = true; moveRef[i] = cur; }
  }
  if (moved) lastMoveAt = now;
  else if (now - lastMoveAt >= AUTO_OFF_MS) {
    DBGLN("Auto off");
    powerDown();
  }
}

//----------------------------------- Setup / loop --------------------------------------//

void setup() {
  // Latch power on first, before anything else can delay us
  pinMode(PWR_PIN, OUTPUT);
  digitalWrite(PWR_PIN, HIGH);

  pinMode(BUTTON_PIN, INPUT_PULLUP);
  pinMode(CC_STAT_PIN, INPUT_PULLUP);
  pinMode(AXL_INT1_PIN, INPUT_PULLUP);
  pinMode(AXL_INT2_PIN, INPUT_PULLUP);
  analogReadResolution(ANA_RES);
  analogReference(ANA_REF);

  DBG_BEGIN();
  DBGLN("Level sensor");

  loadCalibration();
  display_begin();

  if (!accel_begin()) {
    DBGLN("ADXL345 not found");
    display_fill(BAR_BRIGHTNESS, 0, 0);
    display_show();
    delay(1000);
  }

  checkBattery();
  unsigned long now = millis();
  uiMode = UI_BATTERY;
  uiUntil = now + BATT_GAUGE_SHOW_MS;
  lastMoveAt = now;
  nextMoveCheck = now + MOVE_CHECK_MS;
  nextBattCheck = now + BATT_CHECK_MS;
  nextFrame = now;
}

void loop() {
  if (accel_poll() && uiMode == UI_CAL_SAMPLING) calibrationSample();
  pollButton();
  pollMovement();

  unsigned long now = millis();
  if ((long)(now - nextBattCheck) >= 0) {
    nextBattCheck = now + BATT_CHECK_MS;
    checkBattery();
  }
  if ((long)(now - nextFrame) >= 0) {
    nextFrame = now + FRAME_PERIOD_MS;
    if (uiMode == UI_LEVEL || uiMode == UI_GLYPH) updateOrientation();
    render();
#ifdef DEBUG
    static uint8_t dbgDiv = 0;
    if (++dbgDiv >= 20) {
      dbgDiv = 0;
      int16_t c, r; getTilt(c, r);
      DBG("tilt col/row Q4: "); DBG(c); DBG(' '); DBGLN(r);
    }
#endif
  }
}

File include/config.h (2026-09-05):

#pragma once

#include <Arduino.h>

//----------------------------------- Hardware pins ------------------------------------//
#define BATT_VOLTS_PIN    PIN_PA1
#define USB_VOLTS_PIN     PIN_PA2
#define ANA_FLOAT_PIN     PIN_PA4
#define AXL_INT1_PIN      PIN_PA5
#define AXL_INT2_PIN      PIN_PA6
#define LED_DAT_PIN       PIN_PA7      // CCL LUT1 output, SPI0 SCK on PA3 is the bit clock
#define I2C_SCL_PIN       PIN_PB0
#define I2C_SDA_PIN       PIN_PB1
#define UART_TX_PIN       PIN_PB2
#define UART_RX_PIN       PIN_PB3
#define PWR_PIN           PIN_PC0      // drive high to hold main power on
#define LED_PWR_PIN       PIN_PC1      // drive high to power the LED matrix
#define BUTTON_PIN        PIN_PC2      // active low, needs pull-up
#define CC_STAT_PIN       PIN_PC3

//----------------------------------- LED matrix ---------------------------------------//
#define MATRIX_W          8
#define MATRIX_H          7
#define NUM_LEDS          (MATRIX_W * MATRIX_H)
#define FRAME_PERIOD_MS   25           // display refresh (~40 Hz)

// Brightness (0-255 per channel). Keep low: 56 LEDs at full white would draw ~3 A.
#define BUBBLE_BRIGHTNESS 48
#define TICK_BRIGHTNESS   3            // dim edge reference ticks
#define GLYPH_BRIGHTNESS  24
#define BAR_BRIGHTNESS    24

//----------------------------------- Accelerometer ------------------------------------//
#define ADXL345_ADDR      0x53         // SDO/ALT pulled low
#define ACCEL_SAMPLE_MS   10           // 100 Hz, matches ADXL345 BW_RATE setting
#define ACCEL_FILTER_SHIFT 4           // EMA: y += (x - y) >> shift  (tau ~ 160 ms @ 100 Hz)

// Full-resolution mode: 3.9 mg/LSB -> 1 g = ~256 LSB. Small angle: LSB ~= 256*sin(angle)
#define TILT_FULL_SCALE_LSB  45        // ~10 deg = half matrix width
#define TILT_LEVEL_LSB        4.5f     // ~1 deg = "level" (green)
#define TILT_NEAR_LSB        13.4f     // ~3 deg = "near" (amber)

// The button selects which sensor axis is "up" (0 = X, 1 = Y, 2 = Z). For X and Y the sign of
// gravity along that axis is detected automatically, giving 5 cases. Each case defines which
// sensor axis drives the matrix columns/rows (with sign so the bubble travels toward the HIGH
// side) and how the display must be rotated so the UI appears upright to the viewer.
// Case index = axis * 2 + (gravity negative ? 1 : 0); Z uses case 4 only.
enum DisplayRotation : uint8_t {
  ROT_0,          // row 0 at top, col 0 at left (board flat or +Y up)
  ROT_180,        // upside down
  ROT_COL0_TOP,   // board turned so column 0 is at the top
  ROT_COL7_TOP,   // board turned so column 7 is at the top
};
struct AxisMap { uint8_t colAxis; int8_t colSign; uint8_t rowAxis; int8_t rowSign; uint8_t rotation; };
#define NUM_CASES 5
static const AxisMap AXIS_MAP[NUM_CASES] = {
  { 2, -1, 1, -1, ROT_COL0_TOP },   // 0: +X up  cols <- Z, rows <- Y
  { 2, +1, 1, -1, ROT_COL7_TOP },   // 1: -X up  cols <- Z, rows <- Y
  { 0, -1, 2, -1, ROT_0 },          // 2: +Y up  cols <- X, rows <- Z
  { 0, -1, 2, +1, ROT_180 },        // 3: -Y up  cols <- X, rows <- Z
  { 0, -1, 1, -1, ROT_0 },          // 4:  Z up  cols <- X, rows <- Y (flat)
};
#define UP_SIGN_THRESHOLD_LSB 128    // ~0.5 g before the up/down sign is switched

//----------------------------------- Button timing ------------------------------------//
#define BUTTON_DEBOUNCE_MS     30
#define BUTTON_POWER_OFF_MS  2000      // hold 2-5 s then release -> power off
#define BUTTON_CALIBRATE_MS  5000      // hold >5 s then release -> calibrate level

//----------------------------------- Auto power off -----------------------------------//
#define AUTO_OFF_MS          60000UL   // 1 minute of stillness
#define MOVE_CHECK_MS        500
#define MOVE_THRESHOLD_LSB   3         // ~0.7 deg change counts as movement

//----------------------------------- Battery ------------------------------------------//
#define ANA_REF              INTERNAL2V5
#define ANA_RES              10
// Divider is 100k/100k with 2.5 V reference: mV = raw * 5000 / 1024
#define V_BAT_MIN_MV         3400
#define V_BAT_FULL_MV        4150
#define BATT_CHECK_MS        5000
#define BATT_GAUGE_SHOW_MS   700

//----------------------------------- UI timing ----------------------------------------//
#define GLYPH_SHOW_MS        500

//----------------------------------- Calibration --------------------------------------//
#define CAL_COUNTDOWN_MS     5000      // 5..1 countdown so the device can be put down and settle
#define CAL_SAMPLE_MS        1500      // averaging window (150 samples @ 100 Hz)
#define CAL_DONE_MS          800       // "tick" shown after calibration

//----------------------------------- EEPROM -------------------------------------------//
#define EEPROM_MAGIC         0xA5
#define EEPROM_ADDR_MAGIC    0
#define EEPROM_ADDR_CAL      1         // 5 cases x 2 axes x int16 = 20 bytes
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
